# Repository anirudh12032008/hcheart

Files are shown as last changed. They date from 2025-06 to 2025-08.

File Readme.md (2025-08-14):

# Connected Hearts
Connected heart is a project which contains a 3d case and a pcb with esp32, 15rgb leds, buzzer, oled display, a few buttons and a battery with tp4056. The main objective of this project is to create a device which can be used by a group of friends or random people to connect with each other, the esp32 will be connected to a external server from which it will get the data to perform action like playing any sound or turning lights or displaying some messages. Everyone can send there msg on a web server which then be used to trigger these actions on the device. and also show the msg on every device making them connnected without a phone but just a Heart.

## why build connected Heart?
Im currently in high school and going to college next year, and I wanted to create something which can be used by my trio so that we can connect with each other even when not togethere and in the most cool way and also I can use this to impress someone special... And wait its easy to recreate also from the schematic so you can also make it and use it to connect with your friends or someone special.

v1 v4




schem






# Youtube Demo
https://youtu.be/KHVJ3dKNFNE?si=Bhqxjc_PQ0WATk6I

# final build
photo_6102760546496530490_w

https://github.com/user-attachments/assets/06aa9fe9-7b2b-44c4-97bf-056afb49c9ff

## BOM

| Component | Quantity | Cost (INR) | Cost (USD) |
|---|---|---|---|
| PCB | 5 | ₹3032 | $35.15 |
| Case | 2 | ₹870 | $10.00 |
| Display | 3 | ₹660 | $7.59 |
| ESP32 | 3 | ₹960 | $11.03 |
| TP4056 | 3 | ₹48 | $0.55 |
| Toggle Switch | 3 | ₹24 | $0.28 |
| Push Switch | 15 | ₹18 | $0.21 |
| RGB LED | 50 | ₹150 | $1.72 |
| Buzzer | 3 | ₹30 | $0.34 |
| Resistor | – | ₹200 | $2.30 |
| Misc. | – | ₹500 | $5.75 |
| Tax | – | ₹250 | $2.87 |
| Battery And Holder  | 3 | ₹240 | $2.76 |
| Total | – | ₹6947 | $80.55 |

### Why 3?
As the main objective of thisproject is to connect friends and people I need atleast 3 to implement this idea and actually make it useful. The PCB has min 5 and all other component make it less then $10 to create another. I hope you consider this 💖

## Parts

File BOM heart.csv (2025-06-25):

NAME | Quantity | PRICE(INR) | PRICE(USD) | LINK
PCB | 5 | 1500 | 17.24137931 | Estimate Price
Case | 2 | 870 | 10 | Printing Legion
Display | 3 | 660 | 7.586206897 | https://ebhoot.in/shop-2/display-devices/1-3-inch-i2c-iic-4-pin-oled-display-module-with-vcc-gnd-blue/
ESP32 | 3 | 960 | 11.03448276 | https://ebhoot.in/shop-2/esp-wifi-boards/esp32-development-board-type-c-usb-ch340c-wifi-bluetooth-ultra-low-power-dual-core/
TP4056 | 3 | 48 | 0.5517241379 | https://ebhoot.in/shop-2/electronics-modules/bms-module-battery-charging-module/tp4056-1a-li-ion-lithium-battery-charging-module-with-current-protection-type-c/
Toggle Switch | 3 | 24 | 0.275862069 | https://www.importdukan.com/ss12d10-3pin-5mm-straight-feet-toggle-switch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
Push Switch | 15 | 18 | 0.2068965517 | https://ebhoot.in/shop-2/electronics-components/switch-push-button/2pin-round-pushbutton-spst-straight-tactile-micro-switch-through-hole/
RGB LED | 50 | 150 | 1.724137931 | https://ebhoot.in/shop-2/electronics-components/led/5mm-rgb-led-common-cathode-4-pin/
Buzzer | 3 | 30 | 0.3448275862
Resistor |  | 200 | 2.298850575
Misc. |  | 500 | 5.747126437
Tax |  | 250 | 2.873563218
Battery And Holder | 3 | 240 | 2.75862069
Total |  | 5450 | 62.64367816

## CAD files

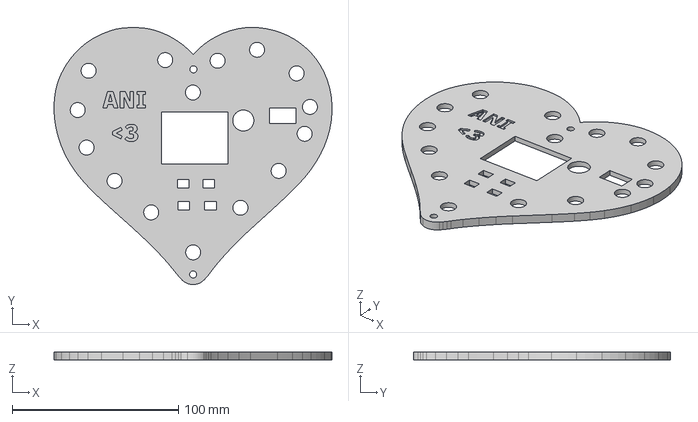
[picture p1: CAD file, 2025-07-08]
cad/TOP_heart.step
167.2 x 154.7 x 5.00 mm

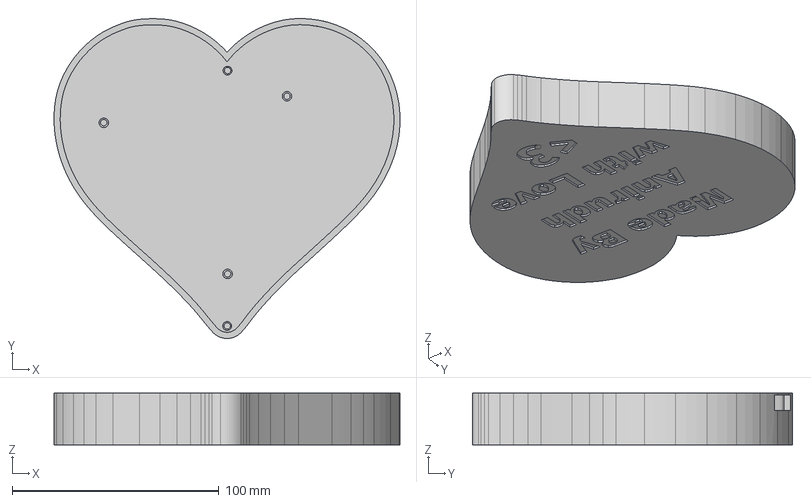
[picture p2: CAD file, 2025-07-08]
cad/bottom_heart.step
167.2 x 154.7 x 25.0 mm

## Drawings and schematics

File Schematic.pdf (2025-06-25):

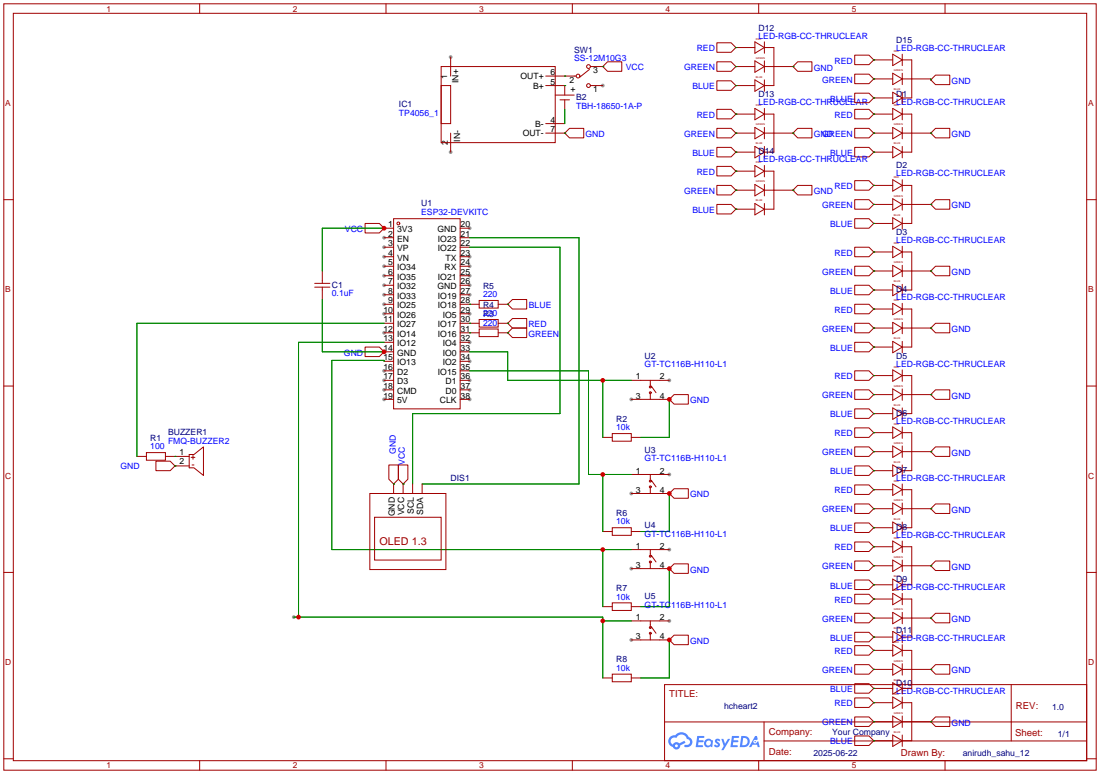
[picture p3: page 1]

LED-RGB-CC-THRUCLEAR

OLED 1.3 GND VCC SCL SDA

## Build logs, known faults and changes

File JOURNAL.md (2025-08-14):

# Connected Hearts

## Journal Title - Connected hearts
Author - Anirudh Sahu
Heart shaped pcb with esp32 as the main heart, 15 RGB led, a buzzer, a display, buttons, 1or 2 3.7V cell . Basically I would need atleast 2 PCBs. The esp32 will be connected to cloud with the help of a external serer hosted on cloud and both of the esp will pull code from it frequently. It would act as a messaging device when one can enter there msg and it would be displayed on both of the PCB, which makes it cool.

Created at - 20 June 2025
Total design Time - 26hr
total build time - 25 hr

## June 20 :- Led Chaser 
Started with making a simple cd4017 and 555 timer led chaser thats in the shape of a heart
worked on it in KiCad, intially searched on web for the details, found multiple projects related to it even started drafting the pcb
cd
Time Spent - 3hr

## June 21:- ATTiny85 integration
I realised that this wouldn't be consider a good project as there is no such new things and such projects are already available., so to make it unique I started to work with attiny85 which could allow me to add more variations in colors and also help me create some logics. Also wrote the program for the attiny to work on and tested it on wokwi
s2
s1
s3
Time Spent - 5hr (till 2 am June22)

## June 22:- Used ESP32 and created the PCB
After knowing that this would be a very limited project I switched to ESP32 as my MC to take the project to next level. This time I had to make things perfect so I started with wokring in KiCad but then I realised my graphics card is broken so I had to switch to easy eda I continued in easy eda along with finding the accutual components to not make it everything SMD I want to create everything by myself. Integrated buzzer, disply, 15 rgb, a few btn and a cell with tp4056. Had to redo the circuit twice due to that KiCAD!!! but succesfully created the schematic and got it reviewed by some hackclubbers on slack and took there suggestions. arranged everything in the pcb and the challenging part was to get the accurate dxf file as in easy eda you cant scale it so had to switch to fusion to edit the dxf then imported it fitted everything in and then completed the routing. after sharing on slack I got some suggestions and motivation to push this project further, im too tired now so ill work on this tommorow. ( succesfully completed the weekend ) 
sch



Time Spent - 6 Hr

## June 24:- Redesigned the PCB
Replaced the OLED with a bigger one, used 4 push buttons instead of one. added a few little things like holes and also using some silk art, designed the whole PCB so that It could fit in a custom case. Researched on the components that have to be used. Shrinked the size of the PCB so re fitted everything in it. Tommorow ill start working on a 3d case to make this project mor cool




Time Spent - 4.5 Hr

## June 25: Created the 3D case and firmware
So I locked in today because I wanted to complete the project and submit it for the design contest, the 3D Case designing was a bit challenging as I had to make sure that everything was in place and the buttons were rechable and there were proper holes for buzzer oled charging esp32. Then I started working on the firmware to quickly draft a basic firware to test the hardwares.v1 v4





Time Spent - 7Hr

# Build
Time - 25 hr
## Day 6
So, today I received my PCB and when I saw the PCB, the obvious flaw that I came to notice is that I was having the wrong MCU. I was having the ESP32 with 30 pins but in the PCB it was of 38 pins and I was really screwed up because I couldn't really return it as I just opened 3 packets of ESP32. So, yeah, I was in a really doubtful situation but I had only one choice. I first searched the internet to find any relevant resources but I couldn't find any. So, my next attempt was to manually fix this design flaw.
So, now I begin fixing what I broke again. So, it was really a major design flaw that I used the 38 pins ESP32 while I bought the 30 pins ESP32. But, it's fine, not fine actually. But, I removed some of the pins from the ESP32 that I was having. Like, those were conflicting with maybe GND or VC. So, I just completely removed them up from the MCU itself. And, I got some red enamel copper wire. So, I used that to create the tracers and jumper wires. And yeah, after troubleshooting a lot of things, most of the things were going right. I had a few issues related to the VCP itself, but after some troubleshooting, it was quite good. So, the ESP did boot up.
I found another major design flaw that the 5V was being used for almost all of the components instead of the 3.3V, which could fry up some of the things. Most of them were rated for 3.3V itself. So I cut the threads for the 5V and I attached the jumper wire to connect the 3V with and after troubleshooting it was good.
The display module was fucked up while soldering it, because I needed to desolder it, as for the 5V problem I thought that it was not necessary. Maybe there was something wrong with the display only, so I began removing it. I thought that it would be as easy as it was inserting it up. But, after doing so, I realized it was completely messed, and I had no options.
So, when I tried removing it, I kind of broke some of the shoulder pads, and it was all really messy, but still I got a bit lucky, because I used another display, and the joints were still not great, but after keeping it at a tilted angle, it worked, and if it works, we shouldn't disturb it and let it just work. So, yeah, currently it's working, the display is working, and I inserted all of the RGB LEDs, and twisted them up, and soldered it, and also I added the buttons there.
photo_6102760546496530534_w
photo_6102760546496530535_w
photo_6102760546496530530_w
photo_6102760546496530533_w
photo_6102760546496530532_w
time spent - 9hr

## Day 7 
Something big was really coming for me. As the RGB LED had really small spacing between their pads. And I wasn't using a fine tip for it. I tried using it but it wasn't working pretty well. So I just used normal tip for the soldering. And I messed up because they were really so close that if I apply solder to one, another one gets automatically connected. I used some desoldering flux but it wasn't really worth it and wasn't really working. Somehow I did manage it and with my multimeter coming to the rescue, I somehow managed it. And it was really a nice thing because when I was using the multimeter, I was seeing that the GND and VCC are getting connected. So it was really good.
Okay, so I read the battery holder and the TP4056 module. And when I started up, it was booting up, and the buzzers were working, the display was working. Just the LEDs were having really, really low brightness. And when I started up, I knew that I needed to use a transistor instead of directly using GPIO pins to give them the current. But as the PCB is already done, I couldn't really modify it now, and I don't even have some 2N double NNN transistors. So, I don't really have a choice right now. And after the TP4056 is attached to it, I noticed that some of the SMD components on it were missing, because while soldering, it just got hot and got removed. So, tomorrow I would work on fixing that up.
I began fixing TP-4056 module that was causing me trouble, but I again messed things up. Instead of putting a SMD component in there, another one got heated and got removed. So I needed to remove the whole module itself. And again, just like the OLED, I fixed the problem here itself. It was all a mess. I took help from my mother to hold things up because I wasn't having the helping hands. So somehow I managed to remove it and put a new one, and it works. It really works now
photo_6102760546496530529_w
photo_6102760546496530526_w
photo_6102760546496530525_w
Time - 7hr

## Day 8 
I began working with the coding part to actually code the logic and create a web server and share the data along it. So I began writing the code and as it's Arduino IDE, it was taking way too much time to compile things up. But after wasting a lot of hours, I finally got it working. I have the web interface which would do the work.
Currently with the web interface, I could send the data to display some text on the OLED screen, change the color of the LEDs, and use some of the RGB combinations to generate some custom colors, buzz the buzzer, and also know the status of all the current pressed buttons. So, it pretty much does everything. Other than that, it's just the firmware that may need to be updated, but currently it's fully functional and working, and as I intended, it has the ability to show the text and change colors, and everything works awesome. I added the switch also, because I messed up with the footprint of the switch itself, but it was manageable to put a small side switch there, so yeah, it's done.
no images because its just code
Time - 6hr

## Day 9 Final assembly
no words only ton of working cutting and glue and yayyyyy
photo_6102760546496530522_w
photo_6102760546496530521_w
photo_6102760546496530490_w
photo_6120626171633846745_w
photo_6120626171633846746_w
time - 3hr

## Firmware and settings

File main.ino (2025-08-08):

#include <WiFi.h>
#include <ESPAsyncWebServer.h>
#include <U8g2lib.h>

// Wi-Fi Credentials
const char* ssid = "Dev Bhai OP";
const char* password = "devbhai123omsairam";

// OLED SH1106
U8G2_SH1106_128X64_NONAME_F_HW_I2C oled(U8G2_R0, U8X8_PIN_NONE, 21, 22);

// Pins
const int BTN1 = 4, BTN2 = 12, BTN3 = 35, BTN4 = 15;
const int BUZZER = 5;
const int RED_PIN = 26, GREEN_PIN = 27, BLUE_PIN = 33;

// State
String oledText = "Welcome ji!";
bool buzzNow = false;
int red = 0, green = 0, blue = 0;

AsyncWebServer server(80);

void setRGB(int r, int g, int b) {
  analogWrite(RED_PIN, r);
  analogWrite(GREEN_PIN, g);
  analogWrite(BLUE_PIN, b);
}

void displayText(String txt) {
  oled.clearBuffer();
  oled.setFont(u8g2_font_logisoso18_tf); // Bigger font
  int tx = (128 - oled.getStrWidth(txt.c_str())) / 2;
  oled.drawStr(tx < 0 ? 0 : tx, 40, txt.c_str());
  oled.sendBuffer();
}

void setup() {
  Serial.begin(115200);
  oled.begin();
  displayText(oledText);

  pinMode(BTN1, INPUT_PULLUP);
  pinMode(BTN2, INPUT_PULLUP);
  pinMode(BTN3, INPUT);
  pinMode(BTN4, INPUT_PULLUP);
  pinMode(BUZZER, OUTPUT);
  pinMode(RED_PIN, OUTPUT);
  pinMode(GREEN_PIN, OUTPUT);
  pinMode(BLUE_PIN, OUTPUT);
  setRGB(0, 0, 0);

  WiFi.begin(ssid, password);
  Serial.print("Connecting to WiFi");
  while (WiFi.status() != WL_CONNECTED) {
    delay(500); Serial.print(".");
  }
  Serial.println("\nConnected! IP: " + WiFi.localIP().toString());

  server.on("/", HTTP_GET, [](AsyncWebServerRequest *request) {
    String html = R"rawliteral(
    <html>
    <body style="font-family:sans-serif">
      <h2>Button States:</h2><pre id='btn'>Loading...</pre>

      <h2>OLED Text:</h2>
      <input type='text' id='msg'><button onclick='sendText()'>Send</button>
      <button onclick='clearText()'>Clear</button>

      <h2>RGB Color (Buttons):</h2>
      <button onclick="setColor('red')">🔴 Red</button>
      <button onclick="setColor('green')">🟢 Green</button>
      <button onclick="setColor('blue')">🔵 Blue</button>
      <button onclick="setColor('white')">⚪ White</button>
      <button onclick="setColor('off')">❌ Off</button>

      <h2>RGB Sliders:</h2>
      R: <input type='range' min='0' max='255' id='r' oninput='sliderRGB()'><br>
      G: <input type='range' min='0' max='255' id='g' oninput='sliderRGB()'><br>
      B: <input type='range' min='0' max='255' id='b' oninput='sliderRGB()'><br>

      <h2>Buzzer:</h2>
      <button onclick="fetch('/buzz')">Buzz!</button>

      <script>
        function sendText() {
          let msg = document.getElementById("msg").value;
          fetch("/oled?msg=" + encodeURIComponent(msg));
        }
        function clearText() {
          fetch("/oled?msg=");
        }
        function setColor(color) {
          fetch("/rgb?color=" + color);
        }
        function sliderRGB() {
          let r = document.getElementById("r").value;
          let g = document.getElementById("g").value;
          let b = document.getElementById("b").value;
          fetch(`/rgb?r=${r}&g=${g}&b=${b}`);
        }
        setInterval(() => {
          fetch("/btn").then(r => r.text()).then(t => {
            document.getElementById("btn").innerText = t;
          });
        }, 1000);
      </script>
    </body></html>
    )rawliteral";
    request->send(200, "text/html", html);
  });

  server.on("/btn", HTTP_GET, [](AsyncWebServerRequest *request) {
    String state = "";
    state += "BTN1: " + String(digitalRead(BTN1) == LOW ? "Pressed" : "Released") + "\n";
    state += "BTN2: " + String(digitalRead(BTN2) == LOW ? "Pressed" : "Released") + "\n";
    state += "BTN3: " + String(digitalRead(BTN3) == HIGH ? "Pressed" : "Released") + "\n";
    state += "BTN4: " + String(digitalRead(BTN4) == LOW ? "Pressed" : "Released") + "\n";
    request->send(200, "text/plain", state);
  });

  server.on("/oled", HTTP_GET, [](AsyncWebServerRequest *request) {
    oledText = request->hasParam("msg") ? request->getParam("msg")->value() : "";
    displayText(oledText);
    request->send(200, "text/plain", "OLED updated");
  });

  server.on("/rgb", HTTP_GET, [](AsyncWebServerRequest *request) {
    if (request->hasParam("color")) {
      String color = request->getParam("color")->value();
      if (color == "red") setRGB(255, 0, 0);
      else if (color == "green") setRGB(0, 255, 0);
      else if (color == "blue") setRGB(0, 0, 255);
      else if (color == "white") setRGB(255, 255, 255);
      else setRGB(0, 0, 0); // off
    } else {
      red = request->hasParam("r") ? request->getParam("r")->value().toInt() : red;
      green = request->hasParam("g") ? request->getParam("g")->value().toInt() : green;
      blue = request->hasParam("b") ? request->getParam("b")->value().toInt() : blue;
      setRGB(red, green, blue);
    }
    request->send(200, "text/plain", "RGB updated");
  });

  server.on("/buzz", HTTP_GET, [](AsyncWebServerRequest *request) {
    buzzNow = true;
    request->send(200, "text/plain", "Buzzed!");
  });

  server.begin();
}

void loop() {
  if (buzzNow) {
    digitalWrite(BUZZER, HIGH);
    delay(150);
    digitalWrite(BUZZER, LOW);
    buzzNow = false;
  }
}

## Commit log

2025-06-25 Added Gerber
2025-06-25 Added Schematic
